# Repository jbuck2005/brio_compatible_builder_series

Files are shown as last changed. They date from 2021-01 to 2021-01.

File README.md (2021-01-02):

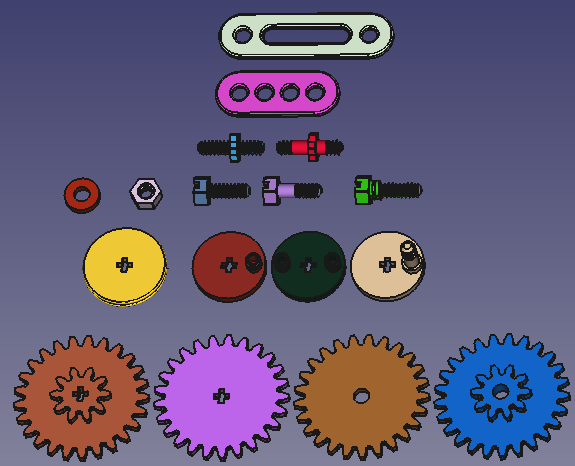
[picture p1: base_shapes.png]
<br>
<h1>brio_compatible_builder_series</h1><br>
Download the FreeCAD project here: <a href="https://github.com/jbuck2005/brio_compatible_builder_series/blob/main/brio_builder_set.FCStd">Brio builder motor set (compatible) expansion kit</a><br>
<br>
STL files are found in the <a href="https://github.com/jbuck2005/brio_compatible_builder_series/tree/main/stl_files">stl_files directory</a><br>
<br>
**Revised & streamlined design for 2021**<br>
<br>
The marketing team is very clever. Our boys received a BRIO Builder ( 34591 ) Builder Motor Set as a shared Christmas gift. In this kit, you get just enough pieces to be fun for a few minutes, but not nearly enough pieces to really make fun stuff. This is where a few hundred dollars of "spare time equivalent" gets spent in CAD to make more pieces for the kiddos without the cognitive expense of having to go shopping (well .. given the current year, let's be honest .. I am NOT going to any stores for anything but essentials).<br>
<br>
The components of this kit are dimensionally based on the aforementioned BRIO builder kit and should be completely compatible. Included are some badly needed "upgrades" and customization. This will be a living project as more components will be added as I dream them up.<br>
<br>
As this design is parametric, the lengths of the beams can be very quickly tailored to your needs. Any directly user editable (critical) dimensions are highlighted with red in the design parameters "spreadsheet" in FreeCAD. Values in green have been proven to be scalable and accurate. Virtually all aspects of each design are editable in the spreadsheet.<br>
<br>
Included are <a href="https://github.com/jbuck2005/brio_compatible_builder_series/tree/master/stl_files">STL files</a> for those who are not yet familiar with <a href="https://github.com/FreeCAD/FreeCAD/blob/master/README.md">FreeCAD</a> include:<br>
<br>
<h2>
<b>
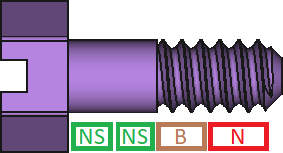
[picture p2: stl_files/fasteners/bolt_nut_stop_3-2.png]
<a href="https://github.com/jbuck2005/brio_compatible_builder_series/blob/master/stl_files/fasteners/">Fasteners</a></b><br>
</h2>
bolt length increments of: 15.5mm (8.5mm for nut, 2.3mm for bolt chamfer) plus 5mm for every beam thickness multiplier<br>
nut in thicknesses increments of <b>8.5mm</b> (17, 25.5, 34mm) - standard kit size is 8.5mm<br>
<code>bolt length = bolt head thickness + nut thickness + (bolt diameter / 4) + (bolt length multiplier x beam thickness)</code><br>
<ul>
<li>bolt lengths: 13.5, 27, 40.5, 54mm</li>
<li>standard bolts</li>
<li>double-sided bolts</li>
<li>bolts with nut-stops (to serve as axles) with additional (nut stop length of 5.5mm)</li>
<li>slotted bolts to fit in beam slots</li>
<li>standard washer</li>
</ul>
<br>
<h2>
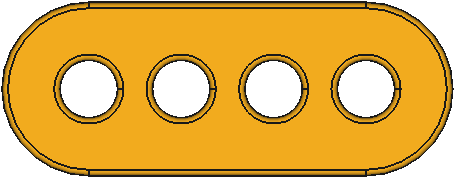
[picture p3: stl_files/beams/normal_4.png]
<b><a href="https://github.com/jbuck2005/brio_compatible_builder_series/blob/master/stl_files/beams/">Beams</a></b><br>
</h2>
beams come in the following hole counts: 3, 4, 5, 6, 7, 8, 9, 10, 11, 12, 1, 14, 16, 18, 20<br>
<b>slotted beams start at 4 hole equivalents</b><br>
<code>beam length = (# holes - 1) x 16mm + 30mm</code><br>
eg. 4 holes = 78mm, 6 holes = 110mm<br>
<ul>
<li>normal beams have holes every 16mm</li>
<li>slotted beams with holes at the ends and a slot spaced 16mm from each hole, running the length</li>
<br>
</ul>
<h2>
<b><a href="https://github.com/jbuck2005/brio_compatible_builder_series/tree/master/stl_files/gears">Gears</a></b><br>
</h2>
<ul>
<li>single cross-driven gear tooth count: 10, 15, 20, 25</li>
<li>single idler gear tooth count: 10, 15, 20, 25</li>
<li>double cross-driven gear tooth count: 10/10, 10/15, 10/20, 10/25, 15/20, 15/25, 20/25</li>
<li>double idler gear tooth count: 10/10, 10/15, 10/20, 10/25, 15/20, 15/25, 20/25</li>
</ul>
<h2>
<b><a href="https://github.com/jbuck2005/brio_compatible_builder_series/tree/master/stl_files/wheels_and_pulleys">Wheels and Pulleys</a></b><br>
</h2>  
the kit drive wheel diameter is 46mm<br>
<ul>
<li>drive wheel single post 46mm</li>
<li>drive wheel double post 46mm</li>
<li>drive wheel single post 46mm (with nut-stop)</li>
<li>v pulleys diameters: 20, 30, 40, _<b>46</b>_, 50, 60, 70mm</li>
</ul>
<br>
The design was done in FreeCAD and as mentioned it is fully parametric. I have included the FreeCAD file so that you can modify the design to your heart's content.<br>
<br>
I am open to any suggestions as to how to improve the design work-flow in FreeCAD.<br>
<br>
<b>This design will be the foundation of a completely open source meccano type set. I am seeking collaborators for this project; if there is enough interest, I will draft up a set of "best practices" and establish some engineering criteria (i.e. standardized dimensions, etc).</b><br>

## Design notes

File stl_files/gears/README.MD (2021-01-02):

<h1><b>Gears</b></h1>
<br>
Gears are involute gears that have been designed to be dimensionally compatible with the Brio builder toy set.<br>
Gears can be broken down into the following categories:
<ol>
  <li>idler - 10mm hole at the center</li>
  <li>cross axle - cross-shaped drive axle center</li>
</ol><br>
Within the main categories, gears can be futher sub-dividied into the following:
<ol>
  <li><a href=#single>single</a></li>
  <li><a href=#double>double</a></li>
</ol>
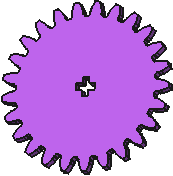
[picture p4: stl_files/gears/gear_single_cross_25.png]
<b><h3>single</h3></b><br>
Single gears are single thickness gears that offer different gear ratios to be developed.<br>
<br>Naming convention: single thickness gears are named for their center profile type (idler vs cross axle) and then their tooth count (in multiples of 5). The image above would be single_cross_25 gear<br>
<br><code>gear diameter = (# teeth) x <a href="https://github.com/jbuck2005/brio_compatible_builder_series/blob/master/brio_builder_set-dimensions.csv">(gear modules)</a></code><br>
<code>note: gear modules has been set to 3.15 to balance strength & finger pinch potential</code><br>
<br>
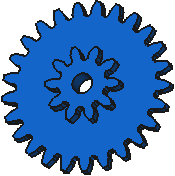
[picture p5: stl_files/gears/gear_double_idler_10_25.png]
<b><h3>double</h3></b><br>
Double gears are stacked gears that offer different gear ratios to be developed.<br>
<br>Naming convention: double gears are named for their central profile type first and then their tooth counts, starting with the smaller count first. If you needed an idler gear (hole at the center) with two different tooth counts, say 10 and 25, you would select the double_idler_10_25 gear. If perhaps you wanted a cross-axle profile at the center and a tooth count of 15 and 20, you would select the double_cross_15_20 gear. The image above would be double_idler_10_25 gear<br>
<br><code>gear diameter = (# teeth) x <a href="https://github.com/jbuck2005/brio_compatible_builder_series/blob/master/brio_builder_set-dimensions.csv">(gear modules)</a></code><br>
<code>note: gear modules has been set to 3.15 to balance strength & finger pinch potential</code><br>

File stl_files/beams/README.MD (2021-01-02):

<h1><b>Beams</b></h1>
Beams are structural building blocks that are dimensionally compatible with the Brio builder toy set.<br>
Beams can be broken down into the following categories:
<ol>
  <li><a href=#normal>normal</a></li>
  <li><a href=#slotted>slotted</a></li>
</ol><br>
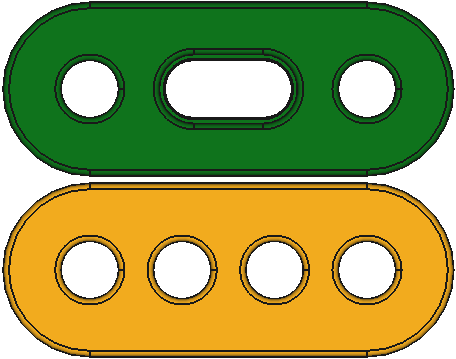
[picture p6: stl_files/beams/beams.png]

<br>
<b><h3>normal</h3></b><br>
Normal beams have holes running the entire length of the shape. Hole (10mm diameter) spacing is 16mm which is half of the spacing found on other parts, which accomodates a greater variety of shapes.<br>
<br>Naming convention: if you require a beam with 4 holes, you would use a normal_4 beam. If instead you need a beam with 8 holes, you would use a normal_8 beam. The image above would be normal_4<br>
<b><br><code>normal beam length = <a href="https://github.com/jbuck2005/brio_compatible_builder_series/blob/master/brio_builder_set-dimensions.csv">(# holes - 1) x 16mm + 30mm</a></code></b><br>
<br>
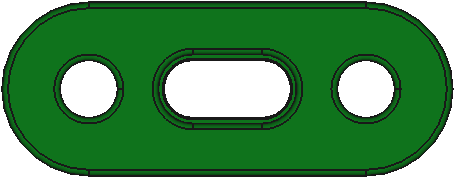
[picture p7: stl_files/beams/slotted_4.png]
<b><h3>slotted</h3></b><br>
Slotted beams are unique in that they do not have holes that run along the length at discrete intervals, instead the entire inner profile is available for mounting objects. Slotted beams allow for a much greater control over build shapes due to the variations afforded.<br>
<br>Naming convention: slotted beams are named after their normal counterparts. If you need a slotted beam with the equivalent length of a 4 hole normal beam, you would use slotted_4 beam. If instead you need a slotted beam with 8 hole equivalents, you would use a slotted_8 beam. The image above would be slotted_4<br>
<br><code>slotted beam length = <a href="https://github.com/jbuck2005/brio_compatible_builder_series/blob/master/brio_builder_set-dimensions.csv">(# holes - 1) x 16mm + 30mm</a></code><br>
<br><b>slotted beams start at 4 hole equivalents due to the geometry of the slotted design</b>
<br>

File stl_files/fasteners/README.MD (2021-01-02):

<h1><b>Fasteners</b></h1>
Fasteners are <a href=#Bolts>bolts</a>, <a href=#Nuts>nuts</a> and <a href=#Washers>washers</a> that are dimensionally compatible with the Brio builder toy set.<br>
<h2>Bolts</h2>
Bolts can be broken down into the following categories:
<ol>
  <li>single headed - hexagonal head with a single threaded shaft</li>
  <li>double headed - two threaded shafts separated by hexagonal shaped fixed washer</li>
  <li>angled - future feature - threaded shafts at discrete angular interections (e.g. two threaded shafts at a 90° angle)</li>
</ol><br>
Within the main categories, bolts can be futher sub-dividied into the following profiles:
<ol>
  <li><a href=#regular>regular</a></li>
  <li><a href=#nut-stop>nut stop</a></li>
  <li><a href=#slotted>slotted</a></li>
  <li><a href=#slotted-nut-stop>slotted nut stop</a></li>
</ol>
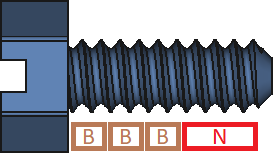
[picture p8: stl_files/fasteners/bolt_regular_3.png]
<b><h3>regular</h3></b><br>
Regular bolts are bolts which lack any additional features. The length of a regular bolt is designed to clamp one beam thickness equivalent for every length multiplier.<br>
<br>Naming convention: if you wish to clamp one beam with a standard bolt, you would use a regular_1 bolt. If you need to clamp two beams,  you would use a regular_2 bolt. The image above would be regular_3<br>
<b><br><code>regular bolt length = <a href="https://github.com/jbuck2005/brio_compatible_builder_series/blob/master/brio_builder_set-dimensions.csv">bolt head thickness + nut thickness + (bolt diameter / 4) + (bolt length multiplier x beam thickness)</a></code></b><br>
<br>
<b><h3>nut stop</h3></b><br>
Nut stop bolts are bolts with a built in non-threaded portion which serves to stop a nut from clamping some distance to the bolt head. These bolts are most useful when serving as "axles" for beams, wheels, pulleys and idler gears.<br>
<br>Naming convention: if you need an axle for a single beam, you would use a nut_stop_1 bolt. If you need an axle for two beams, you would use a nut_stop_2 bolt. Any number following an 'n-dash' (\-) indicates the nut stop length. For example, say you needed a bolt which was able to accomodate 5 beam thicknesses, but wished to have the nut stop serve as an axle for 2 beams, you would use a nut_stop_5-2 bolt. The image above would be nut_stop_3-2<br>
<br><code>nut stop bolt length = regular bolt length + <a href="<a href="https://github.com/jbuck2005/brio_compatible_builder_series/blob/master/brio_builder_set-dimensions.csv">(nut stop length x nut stop multiplier)</a></code><br>
<br>
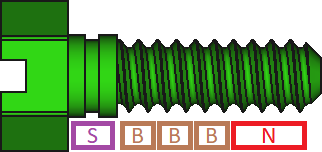
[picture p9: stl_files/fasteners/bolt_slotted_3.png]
<b><h3>slotted</h3></b><br>
Slotted bolts have an oval neck profile immediately below the bolt head that allows the bolt to be retained in a slotted beam. These bolts can be used to clamp an object anywhere along the slot length.<br>
<br>Naming convention: if you wish to clamp one beam with a slotted bolt, you would use a slotted_1 bolt. If you need to clamp two beams,  you would use a slotted bolt.  The image above would be slotted_3<br>
<br><code>slotted bolt length = regular bolt length + <a href="https://github.com/jbuck2005/brio_compatible_builder_series/blob/master/brio_builder_set-dimensions.csv">beam thickness</a></code><br>
<br>
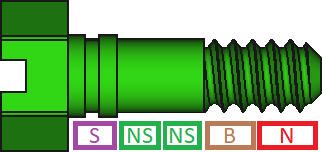
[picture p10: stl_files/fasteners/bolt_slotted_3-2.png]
<b><h3>slotted nut stop</h3></b><br>
Slotted nut stop bolts have an oval neck profile immediately below the bolt head as well as a nut stop profile, allowing the slotted bolt to slide along a beam slot while acting as an axle.<br>
<br>Naming convention: Any number following an an 'n-dash' (\-) indicates the nut stop length. For example, say you needed a bolt which was able to accomodate 5 beam thicknesses, but wished to have the nut stop serve as an axle for 2 beams, you would use a slotted_nut_stop_5-2 bolt. The image above would be slotted_nut_stop_3-2<br>
<br><code>slotted nut stop bolt length = regular bolt length + beam thickness + (nut stop length x nut stop multiplier)</code>
<h2>Nuts</h2>
Nuts are standard clamping hardware that come in a variety of thicknesses.
<h2>Washers</h2>
Washers are available in incremental thicknesses with standardized inner and outer diameters.

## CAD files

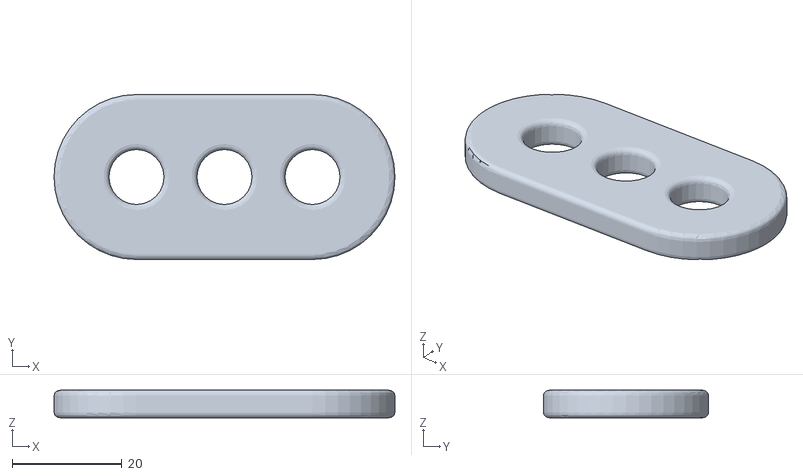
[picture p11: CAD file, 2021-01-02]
stl_files/beams/beam_normal_03.stl
62.0 x 30.0 x 5.00

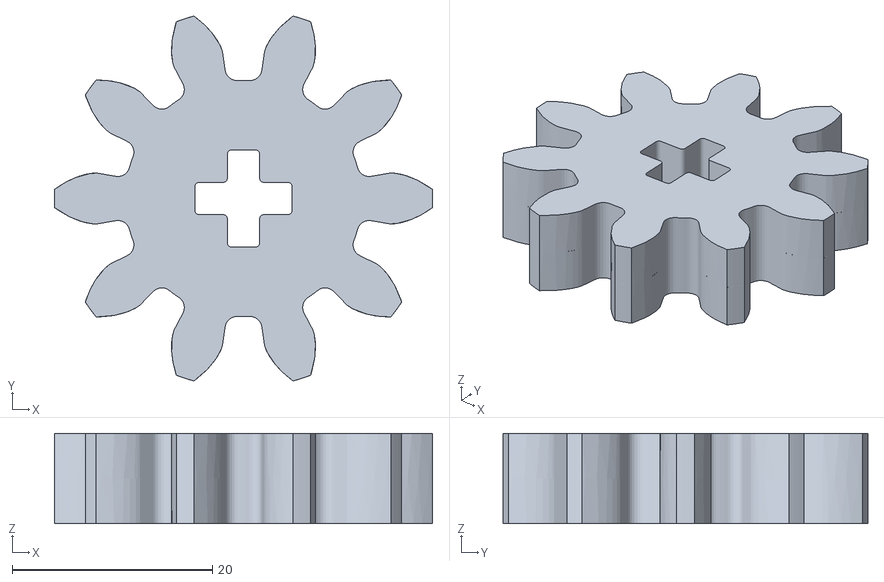
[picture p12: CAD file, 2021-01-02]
stl_files/gears/gear_double_cross_10_10.stl
37.8 x 36.5 x 9.00

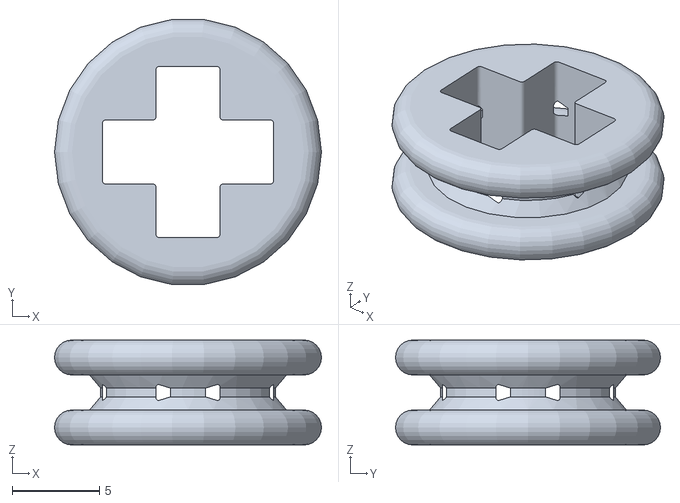
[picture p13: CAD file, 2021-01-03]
stl_files/wheels_and_pulleys/pulley_v_10mm.stl
15.3 x 15.1 x 6.00

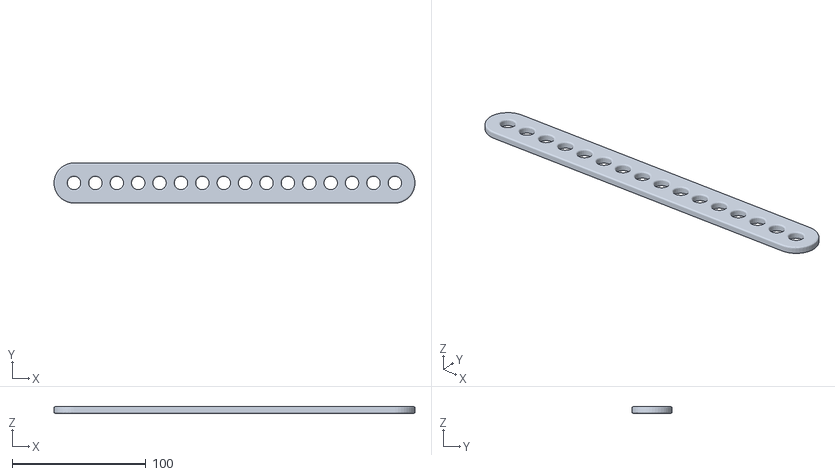
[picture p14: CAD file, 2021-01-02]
stl_files/beams/beam_normal_16.stl
270.0 x 30.0 x 5.00

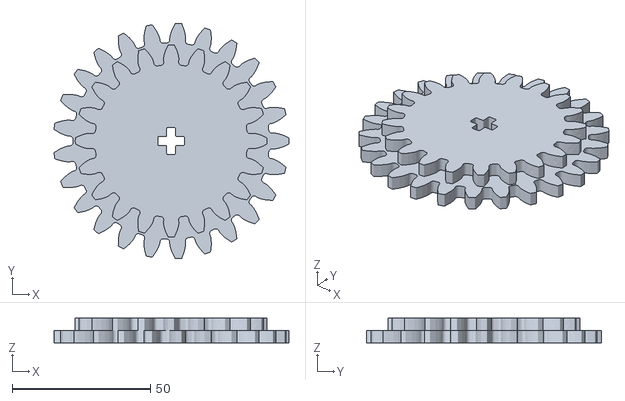
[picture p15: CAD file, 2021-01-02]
stl_files/gears/gear_double_cross_20_25.stl
84.8 x 85.0 x 9.00

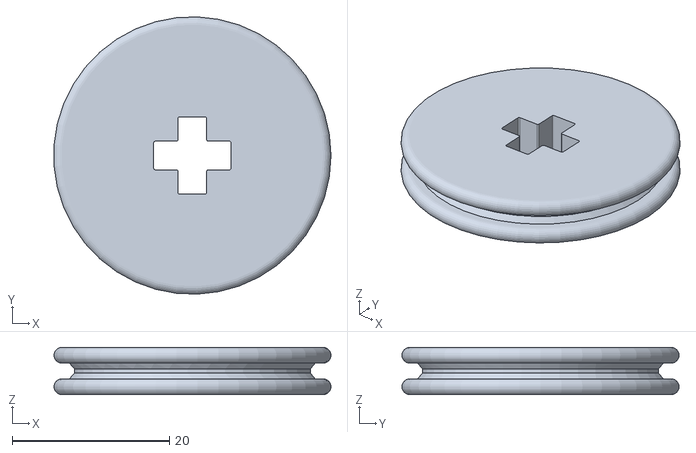
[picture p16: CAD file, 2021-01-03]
stl_files/wheels_and_pulleys/pulley_v_30mm.stl
35.2 x 35.2 x 6.00

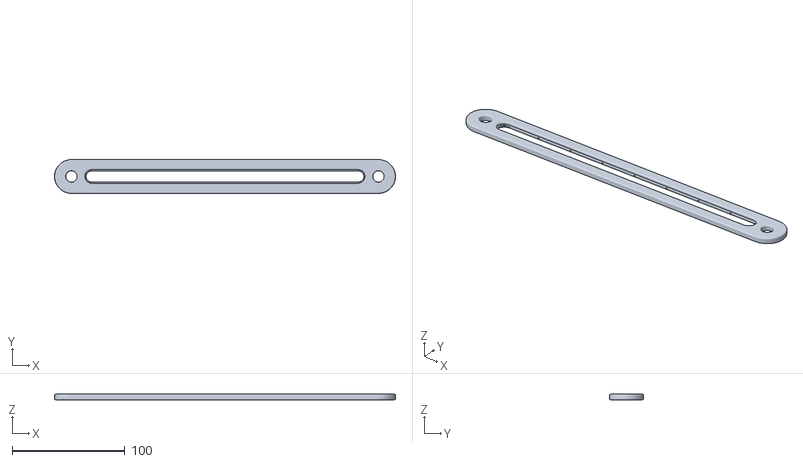
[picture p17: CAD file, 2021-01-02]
stl_files/beams/beam_slotted_18.stl
302.0 x 30.0 x 5.00

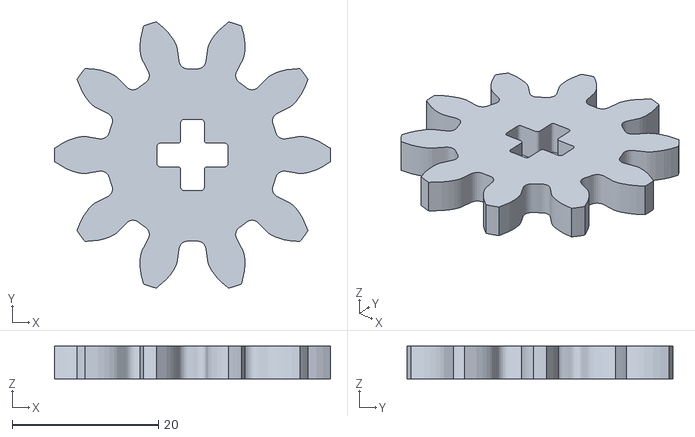
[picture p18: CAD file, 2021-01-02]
stl_files/gears/gear_single_cross_10.stl
37.8 x 36.5 x 4.50

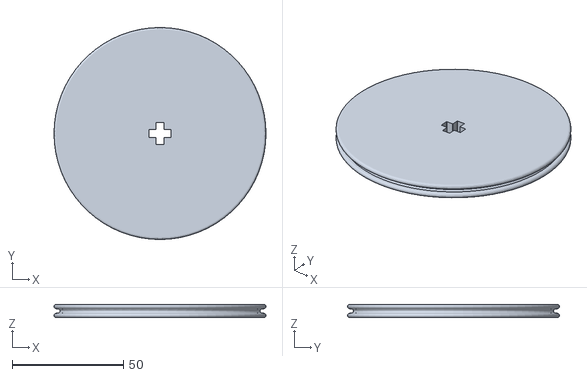
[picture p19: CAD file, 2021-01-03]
stl_files/wheels_and_pulleys/pulley_v_90mm.stl
95.3 x 95.3 x 6.00

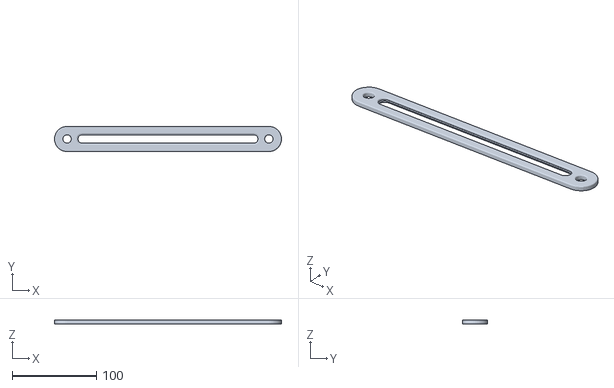
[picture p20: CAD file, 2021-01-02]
stl_files/beams/beam_slotted_16.stl
270.0 x 30.0 x 5.00

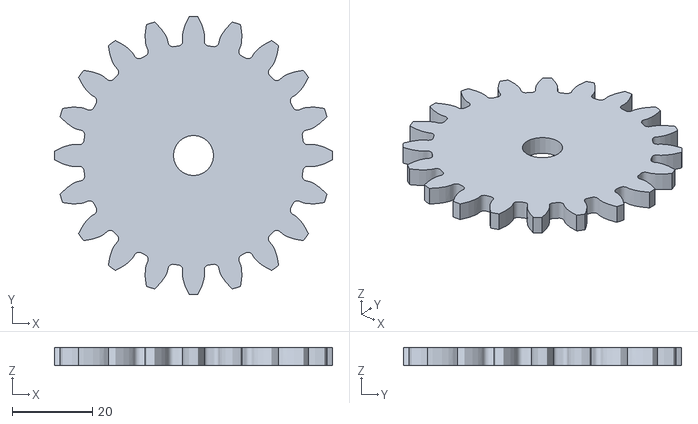
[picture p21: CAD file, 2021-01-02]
stl_files/gears/gear_single_idler_20.stl
69.3 x 69.3 x 4.50

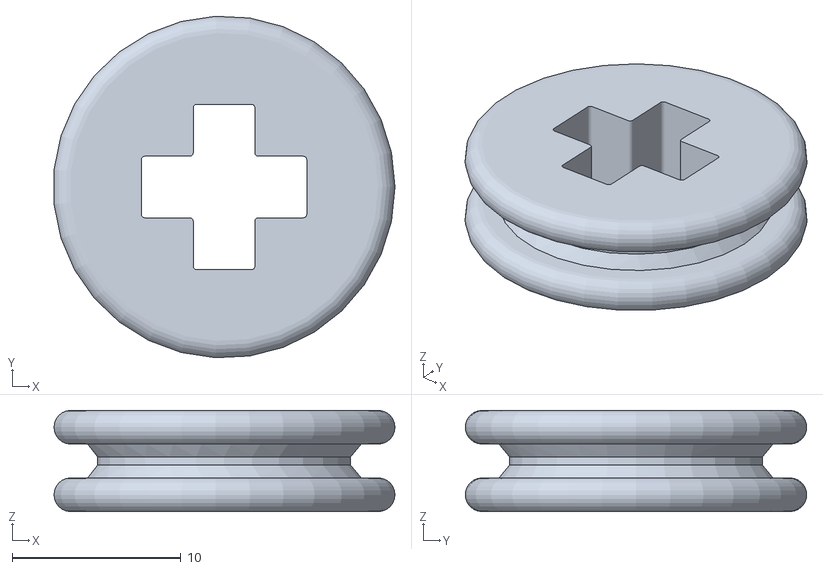
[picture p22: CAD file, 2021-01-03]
stl_files/wheels_and_pulleys/pulley_v_15mm.stl
20.2 x 20.2 x 6.00

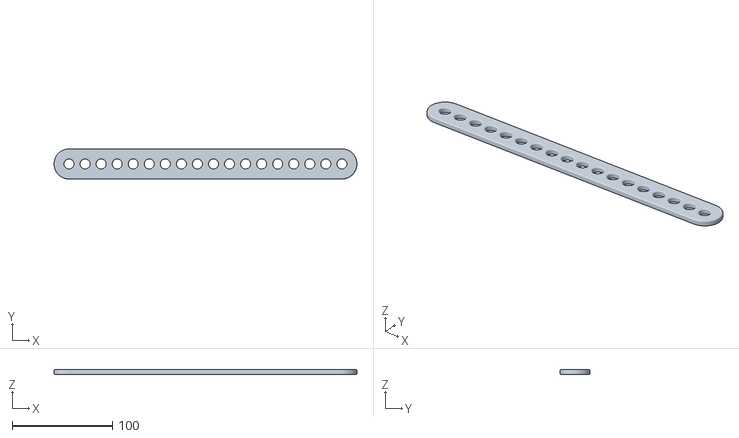
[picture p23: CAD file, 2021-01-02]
stl_files/beams/beam_normal_18.stl
302.0 x 30.0 x 5.00

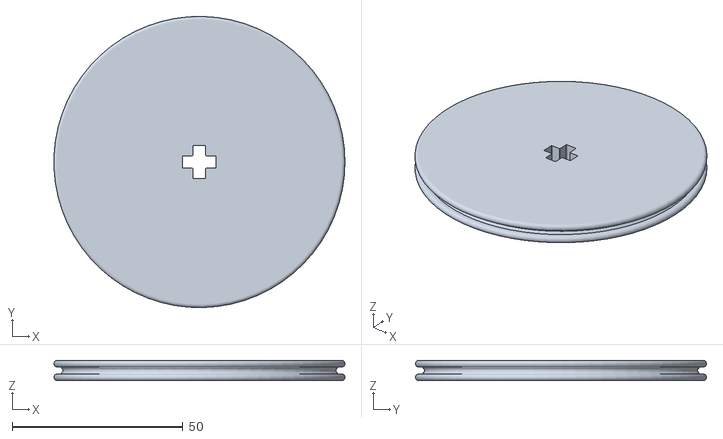
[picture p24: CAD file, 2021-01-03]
stl_files/wheels_and_pulleys/pulley_v_80mm.stl
85.2 x 85.2 x 6.00

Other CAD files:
stl_files/gears/gear_single_idler_10.stl
stl_files/beams/beam_slotted_20.stl
stl_files/gears/gear_double_idler_20_25.stl
stl_files/wheels_and_pulleys/pulley_v_60mm.stl
stl_files/beams/beam_normal_04.stl
stl_files/beams/beam_normal_05.stl
stl_files/beams/beam_normal_06.stl
stl_files/beams/beam_normal_07.stl
stl_files/beams/beam_normal_08.stl
stl_files/beams/beam_normal_09.stl
stl_files/beams/beam_normal_10.stl
stl_files/beams/beam_normal_12.stl
stl_files/beams/beam_normal_14.stl
stl_files/beams/beam_normal_20.stl
stl_files/beams/beam_slotted_04.stl
stl_files/beams/beam_slotted_05.stl
stl_files/beams/beam_slotted_06.stl
stl_files/beams/beam_slotted_07.stl
stl_files/beams/beam_slotted_08.stl
stl_files/beams/beam_slotted_09.stl
stl_files/beams/beam_slotted_10.stl
stl_files/beams/beam_slotted_12.stl
stl_files/beams/beam_slotted_14.stl
stl_files/fasteners/bolt_double_nut_stop_1-0_1-1.stl
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

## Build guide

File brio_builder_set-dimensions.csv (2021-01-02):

printer tolerance | 0.2 | pulley diameter | 46 | bolt length multiplier | 3 | double bolt length multiplier L | 1 | gear size multiplier (upper) | 2
normal beam hole count | 4 | wheel diameter |  | nut thickness multiplier | 1 | double bolt length multiplier R | 2 | gear size multiplier (lower) | 5 | (use for single)
slotted beam hole count | 6 |  |  | nut stop multiplier | 2 | double nut stop multiplier L | 1
 |  |  |  |  |  | double nut stop multiplier R | 2
normal beam length | 78 | slotted beam length | 110 | total bolt length | 19.25 | total double bolt length | 19.5 | teeth per diameter ratio | 5
hole diameter | 10 | drive wheel diameter | 46.1 | thread pitch (metric) | 2.4 | nut thickness | 8.5 | total gear teeth 1 | 10
hole spacing | 16 | drive wheel thickness max | 5 | thread nose radius | 0.6 | bolt length regular | 10.8 | total gear teeth 2 | 25
beam thickness | 5 | drive wheel thickness min | 5 | bolt thread stop length | 1.25 | bolt length nut stop | 12.05 | gear modules | 3.15
beam width | 30 | drive wheel post length | 10.2 | bolt diameter | 9.2 | bolt length slot | 15.8 | gear thickness | 4.5
beam length per hole | 31.3571 | dirve wheel post width | 9.15 | bolt flats width | 16.8 | bolt length slot nut stop | 17.05
effective normal holes | 3 | drive wheel post height | 8 | bolt thread inner diameter | 7 | single bolt length | 15 | wheel v outer diameter | 44.8
effective slotted holes | 5 | drive wheel post ring height | 4 | bolt head thickness | 8.45 | double bolt length L | 5 | wheel v inner diameter | 3.75
beam fillet radius | 1 | drive wheel post right cut height | 1.25 | bolt head hole diameter | 5.8 | double bolt length R | 10 | wheel thickness posts | 9.12
 |  | drive wheel post notch width | 2 | bolt head slot width | 4 |  |  | wheel thickness body | 7.62
cross axle width | 9.5 |  |  | bolt head inner slot length | 9.2 |  |  | wheel thickness web | 1.32
cross axle wall width | 3.4 | pulley v angle | 50 | bolt head inner slot depth | 6.8 | nut flats width | 16.8
cross axle fillet radius | 0.4 | pulley thickness | 6 | bolt head outer slot depth | 3.2 | nut inner diameter | 8
 |  |  |  | bolt head radius | 0.6 | washer thickness | 4.5
slotted notch width | 0.8 |  |  | bolt end chamfer angle | 45 | washer diameter | 21.9
slotted notch height | 1
slot width / diameter | 12
beams Y axis | 220 | drive wheel Y axis | 100 | fasteners Y axis | 150 | gear Y axis | 178.54

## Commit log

2021-01-02 Add files via upload
    initial upload of beams
    [beam_normal_10.stl, beam_normal_12.stl, beam_normal_14.stl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]
2021-01-02 Add files via upload
    renamed, adding leading 0 for better sorting
    [beam_normal_03.stl, beam_normal_04.stl, beam_normal_05.stl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]
2021-01-02 Add files via upload
    initial upload
    [bolt_double_nut_stops_1_1.stl, bolt_double_nut_stops_1_2.stl, bolt_double_nut_stops_1_3.stl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]
2021-01-02 fixed file naming
    [bolt_slotted_nut_stop_2-1.stl, brio_builder_set-dimensions.csv]
2021-01-02 refresh repo version
    [gear_double_idler_10_25.stl]
2021-01-02 added wheels and pulleys
2021-01-02 corrected double wheel colour
2021-01-02 updated beams
    [beam_normal_04.stl, beam_normal_05.stl, beam_normal_06.stl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]
2021-01-02 update gears
    [gear_double_cross_10_10.stl, gear_double_cross_10_15.stl, gear_double_cross_10_20.stl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]
2021-01-03 fastener update
    [bolt_double_nut_stop_1-0_1-1.stl, bolt_double_nut_stop_1-0_2-1.stl, bolt_double_nut_stop_1-0_2-2.stl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]
2021-01-03 remove defective STL
    [pulley_v_20mm.stl, pulley_v_30mm.stl, pulley_v_46mm.stl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]
2021-01-03 added comonents & improved cross profile
    [bolt_double_nut_stop_2-0_2-1.stl, bolt_double_nut_stop_2-0_2-2.stl, bolt_double_nut_stop_2-0_3-1.stl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]
